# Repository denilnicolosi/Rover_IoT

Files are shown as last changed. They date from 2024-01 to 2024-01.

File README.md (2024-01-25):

# Rover_IoT
Progetto per il corso di Sistemi Operativi, implementazione di un rover con ESP32 e FreeRTOS che comunica mediante protocollo MQTT con una interfaccia web.

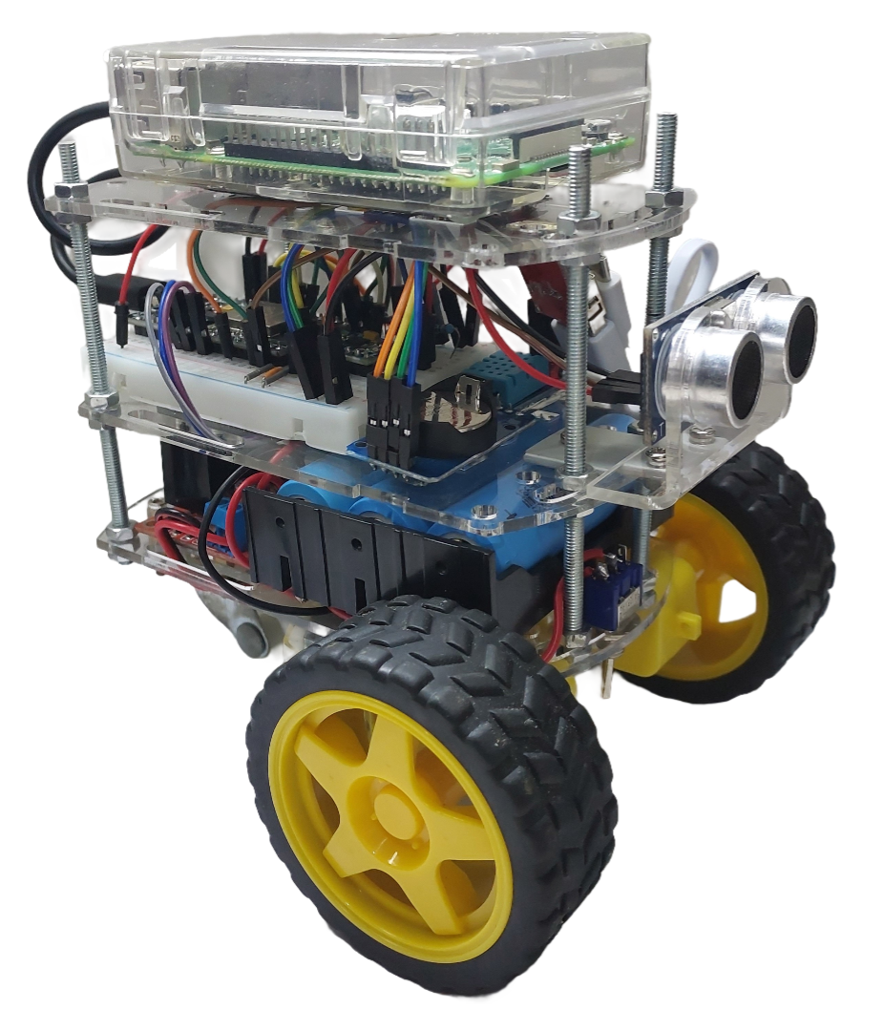
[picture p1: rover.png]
Rover


## Avvio Rapido
Per riprodurre il progetto in tutte le sue parti, realizzare il seguente schema elettrico:
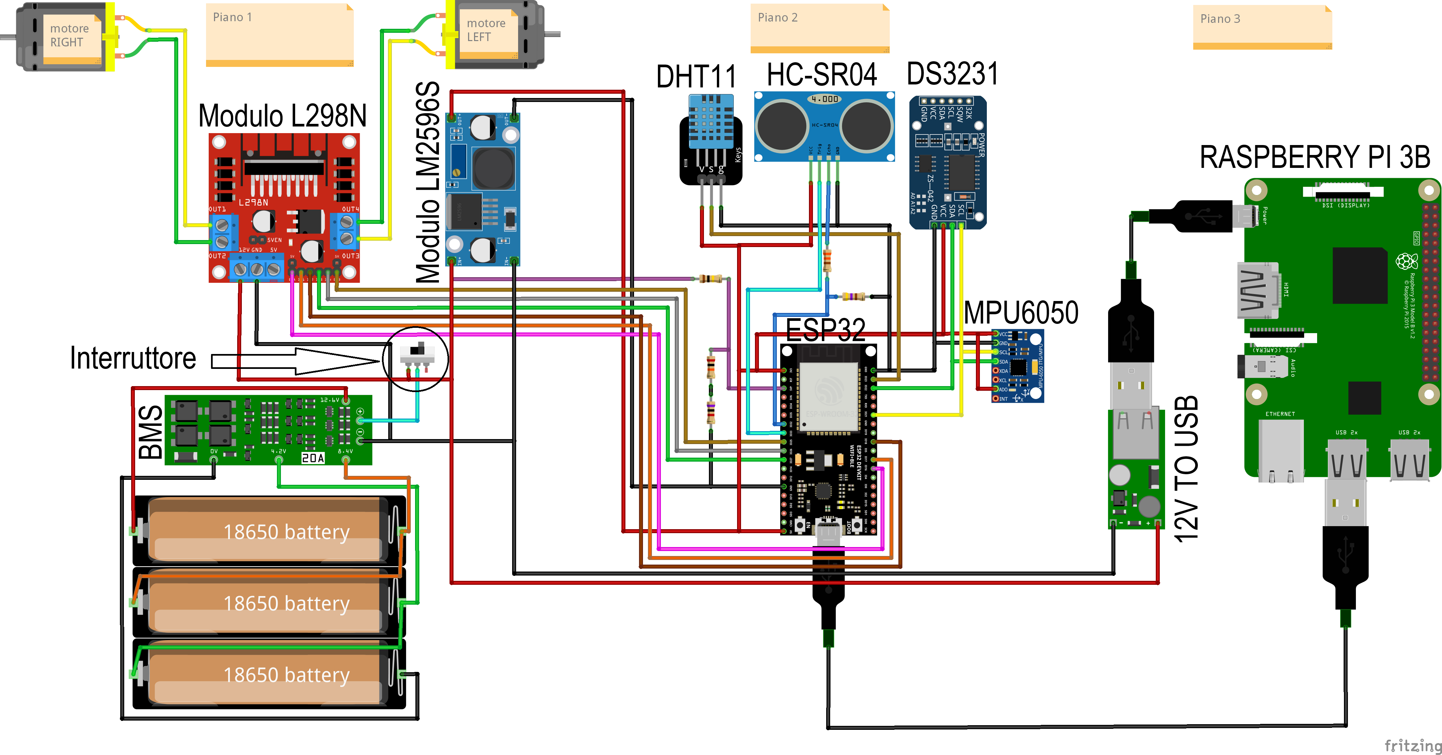
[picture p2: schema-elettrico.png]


Per avviare il progetto seguire i seguenti passaggi:
1. Clona il repository: `git clone https://github.com/denilnicolosi/Rover_IoT`
2. Naviga nella directory del progetto: `cd Rover_IoT`
3. Scaricare e avviare l'[IDE di Arduino](https://www.arduino.cc/en/software).
4. Aprire il [codice sorgente](ESP32/progetto_so.ino) dell'ESP32
5. Installare, tramite il gestore delle librerie, le seguenti dipendenze:
    - Adafruit_MPU6050: https://github.com/adafruit/Adafruit_MPU6050
    - Adafruit_Sensor: https://github.com/adafruit/Adafruit_Sensor
    - DS3231: https://github.com/NorthernWidget/DS3231
    - HCSR04: https://github.com/Martinsos/arduino-lib-hc-sr04
    - L298N: https://github.com/AndreaLombardo/L298N
    - DHT: https://github.com/adafruit/DHT-sensor-library
    - ArduinoJson: https://arduinojson.org/?utm_source=meta&utm_medium=library.properties
6. Eseguire l'upload del codice nell'ESP32.
7. Installare il sistema operativo Raspberry Pi OS nella memoria SD dedicata, utilizzando il [seguente tool](https://www.raspberrypi.com/software/) e inserire eventuali configurazioni (come nome utente, password e rete wifi)
8. Inserire la memoria SD nella Raspberry e dopo il primo avvio, creare un file python con il [seguente codice](Raspberry/mqtt_client.py) .
NB: nella funzione `client.connect()` va inserito l'hostname (o indirizzo IP) del broker MQTT configurato in seguito.
9. Per individuare la porta USB da inserire nella funzione `serial.Serial()`, è possibile utilizzare il [seguente codice](Raspberry/print_serial_port.py).
10. Creare il servizio per l'avvio automatico dello script, inserendo il file di configurazione [mqtt_client.service](mqtt_client.service) nel percorso predefinito `/lib/systemd/system/`.
11. Abilitare il servizio eseguendo in ordine i seguenti comandi:
    ```
    > sudo systemctl daemon-reload
    > sudo systemctl enable mqtt client.service
    > sudo systemctl start mqtt client.service
    > sudo systemctl status mqtt client.service
    ```
12. Creare una macchina virtuale Ubuntu, ad esempio utilizzando [VMware Workstation Player](https://www.vmware.com/it/products/workstation-player.html).
13. Installare il broker MQTT mosquitto con il comando `sudo apt install mosquitto mosquitto-clients`.
14. Da Ubuntu Software Center installare il pacchetto `node-red` e `mysql-workbench-community`.
15. Installare e configurare mysql con i seguenti comandi:
```
> sudo apt install mysql-server
> sudo systemctl start mysql.service
> sudo mysql
```
16. Impostare la password di root con il seguente comando:
```
mysql> ALTER USER 'root'@'localhost' IDENTIFIED WITH mysql_native_password BY 'pass';
mysql> exit;
```
17. Eseguire lo script per la configurazione in sicurezza:
```
sudo my_sql_secure_installation
```
18. Quindi creare un nuovo utente mysql per l'utilizzo dell'applicazione
```
> mysql -u root -p
mysql> CREATE USER 'nodered'@'localhost' IDENTIFIED BY 'n0dep4assw0rd';
mysql> GRANT PRIVILEGE ON *.* TO 'nodered'@'localhost';
mysql> FLUSH PRIVILEGES;
```
19. Creare il database con il comando:
```
mysql> CREATE DATABASE nodered;
```
20. Quindi creare la tabella con la query DDL:
```
mysql> CREATE TABLE 'nodered'.'sensors_history' (
        'id' INT NOT NULL AUTO_INCREMENT,
        'distance' DOUBLE NULL,
        'acceleration_x' DOUBLE NULL,
        'acceleration_y' DOUBLE NULL,
        'acceleration_z' DOUBLE NULL,
        'rotation_x' DOUBLE NULL,
        'rotation_y' DOUBLE NULL,
        'rotation_z' DOUBLE NULL,
        'timestamp' DATETIME NULL,
        'temperature' DOUBLE NULL,
        'humidity' DOUBLE NULL,
        'battery_voltage' DOUBLE NULL,
        PRIMARY KEY ('id'),
        UNIQUE INDEX 'id_UNIQUE' ('id' ASC) VISIBLE);
```
21. Accedere poi a Node-RED digitando nel browser il seguente indirizzo: `http://localhost:1880`

22. Installare, tramite 'Manage palette' le librerie:
    - node-red-dashboard
    - node-red-node-mysql

23. Importare la configurazione [dashboard.json](Node-RED/dashboard.json) cliccando sul menù la voce 'import'.
24. La dashboard sarà accessibile all'indirizzo `http://localhost:1800/ui`

Tutti gli approfondimenti per l'installazione si trovano nella [relazione del progetto](Relazione.pdf).

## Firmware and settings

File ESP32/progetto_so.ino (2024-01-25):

#include <Adafruit_MPU6050.h>
#include <Adafruit_Sensor.h>
#include <Wire.h>
#include <DS3231.h>
#include <HCSR04.h>
#include <L298N.h>
#include <DHT.h>
#include <ArduinoJson.h>

// Definizione dei pin GPIO ESP32
#define HCSR04_TRIGGER_PIN 32
#define HCSR04_ECHO_PIN 33
#define DHT11_PIN 23
#define BATTERY_PIN 36
#define L_MOTOR_EN_PIN 25
#define L_MOTOR_IN1_PIN 26
#define L_MOTOR_IN2_PIN 27
#define R_MOTOR_EN_PIN 16
#define R_MOTOR_IN1_PIN 17
#define R_MOTOR_IN2_PIN 18

// Defininizione delle costanti utilizzate
#define DELAY_SEND_SENSOR_DATA_MS 2000
#define DELAY_FUNCTION_MODE_MS 50
#define DELAY_RECEIVE_DATA_MS 100
#define SAFETY_DISTANCE_CM 20

// Dichiarazione degli oggetti utilzzati
Adafruit_MPU6050 mpu;
RTClib myRTC;
DS3231 myClock;
DHT dht11(DHT11_PIN, DHT11);
L298N l_motor(L_MOTOR_EN_PIN, L_MOTOR_IN1_PIN, L_MOTOR_IN2_PIN);
L298N r_motor(R_MOTOR_EN_PIN, R_MOTOR_IN1_PIN, R_MOTOR_IN2_PIN );
UltraSonicDistanceSensor distanceSensor(HCSR04_TRIGGER_PIN, HCSR04_ECHO_PIN); 
StaticJsonDocument<250> docOutput; // Utilizzato il tool https://arduinojson.org/v6/assistant per calcolare la capacità del documento json.
StaticJsonDocument<250> docInput;

//definizione del semaforo
SemaphoreHandle_t xMutex;

// Variabili ed enum utilizzati
sensors_event_t a, g, temp;

enum function_mode{
  AUTO = 0 ,
  MAN = 1
} function_mode_selected;

enum command{
  FORWARD = 0,
  BACKWARD = 1,
  RIGHT = 2,
  LEFT = 3,
  STOP = 4
} command_received;


void taskFunctionMode(void *pvParameters){
  TickType_t xLastWakeTime = xTaskGetTickCount();
  while (1){    
    if(function_mode_selected == AUTO){
      xSemaphoreTake(xMutex, portMAX_DELAY);      
      if(distanceSensor.measureDistanceCm()<=SAFETY_DISTANCE_CM){
        r_motor.stop();
        l_motor.stop();
        vTaskDelay(500 / portTICK_PERIOD_MS);      
        //random rotate
        r_motor.forward();
        l_motor.backward();
        vTaskDelay(random(300,800) / portTICK_PERIOD_MS);
        r_motor.stop();
        l_motor.stop();
        vTaskDelay(500 / portTICK_PERIOD_MS);  
      }else{
        r_motor.forward();
        l_motor.forward();    
      } 
      xSemaphoreGive(xMutex);     
    }
    else
    {  
      switch(command_received){
        case FORWARD:
            xSemaphoreTake(xMutex, portMAX_DELAY);
            if(distanceSensor.measureDistanceCm()<=SAFETY_DISTANCE_CM){            
              r_motor.stop();
              l_motor.stop(); 
            }else{              
              r_motor.forward();
              l_motor.forward();
            } 
            xSemaphoreGive(xMutex);         
          break;
        case BACKWARD:
          r_motor.backward();
          l_motor.backward(); 
          break;
        case RIGHT:
          r_motor.backward();
          l_motor.forward(); 
          break;
        case LEFT:
          r_motor.forward();
          l_motor.backward(); 
          break;
        case STOP:
          r_motor.stop();
          l_motor.stop(); 
          break;  

        default:
          r_motor.stop();
          l_motor.stop(); 
          
      }      
    }
    vTaskDelayUntil( &xLastWakeTime, pdMS_TO_TICKS(DELAY_FUNCTION_MODE_MS));    
  }
}


void taskRiceviDati(void *pvParameters){
  TickType_t xLastWakeTime = xTaskGetTickCount();
  while (1){    
    if(Serial.available()){
      DeserializationError err = deserializeJson(docInput, Serial);
      if (err == DeserializationError::Ok) 
      {      
        if(!docInput["rtc_sync_unixtime"].isNull()){                   
          time_t epoch = (time_t)docInput["rtc_sync_unixtime"].as<long>();
          myClock.setEpoch(epoch);
        }
        if(!docInput["function_mode_auto"].isNull()){
          if(docInput["function_mode_auto"].as<String>()=="true"){
            function_mode_selected=AUTO;          
          }else{
            function_mode_selected=MAN;            
          }
        }
        if(!docInput["movement_command"].isNull()){
          command_received = (command) docInput["movement_command"].as<int>();         
        }
        if(!docInput["speed"].isNull()){
          int speed=docInput["speed"].as<int>();
          if(speed>0 && speed<=100){
            //mapping della velocità che viene ricevuta in 0-100% al range pwm in 0-255
            speed = map(speed, 0, 100, 0, 255);
            l_motor.setSpeed(speed);
            r_motor.setSpeed(speed);           
          }
        }
      } 
      else 
      {        
        // Flush all bytes in the "link" serial port buffer
        while (Serial.available() > 0)
          Serial.read();
      }
    }
    vTaskDelayUntil( &xLastWakeTime, pdMS_TO_TICKS(DELAY_RECEIVE_DATA_MS));       
  }
}

void taskInvioDati(void *pvParameters){
  TickType_t xLastWakeTime = xTaskGetTickCount();
  while (1){    
    mpu.getEvent(&a, &g, &temp);   
    xSemaphoreTake(xMutex, portMAX_DELAY);
    docOutput["distance"]=distanceSensor.measureDistanceCm();
    xSemaphoreGive(xMutex);
    docOutput["acceleration"]["x"]=a.acceleration.x;
    docOutput["acceleration"]["y"]=a.acceleration.y;
    docOutput["acceleration"]["z"]=a.acceleration.z;
    docOutput["rotation"]["x"]=g.gyro.x;
    docOutput["rotation"]["y"]=g.gyro.y;
    docOutput["rotation"]["z"]=g.gyro.z;
    docOutput["unixtime"]=myRTC.now().unixtime();
    docOutput["temperature"]=dht11.readTemperature(); 
    docOutput["humidity"]=dht11.readHumidity();
    docOutput["battery"]["voltage"]=readVoltage();
    serializeJson(docOutput, Serial);
    Serial.println();

    vTaskDelayUntil( &xLastWakeTime, pdMS_TO_TICKS(DELAY_SEND_SENSOR_DATA_MS)); 
  }
}

float readVoltage(){
  return (float)analogRead(BATTERY_PIN) / 4096 * 17 ;
}

void setup(void) {
  Serial.begin(115200); 
  Wire.begin();  
  if (!mpu.begin(0x69)) {
    Serial.println("Failed to find MPU6050 chip");  
  }else{
    Serial.println("MPU6050 Found!"); 
  }
  dht11.begin();  

  function_mode_selected=MAN;
  command_received=STOP;
  l_motor.setSpeed(70);
  r_motor.setSpeed(70);

  xMutex = xSemaphoreCreateMutex();
  
  xTaskCreate(taskRiceviDati, "Task ricezione dati", 5000, NULL, 2, NULL);  
  xTaskCreate(taskFunctionMode, "Task modalità di funzionamento", 5000, NULL, 3, NULL);
  xTaskCreate(taskInvioDati, "Task invio dati", 5000, NULL, 1, NULL);
}

void loop () {}

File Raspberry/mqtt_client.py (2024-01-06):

import serial
import simplejson as json
import paho.mqtt.client as mqtt

def on_connect(client, userdata, flags, rc):
    print("Connected to host '", client._host, "'") 
    client.subscribe("movement_command")
    client.subscribe("speed")
    client.subscribe("function_mode_auto")
    client.subscribe("rtc_sync_unixtime")

def on_message(client, userdata, msg):
    #write to serial port json with key msg.topic and value msg.payload
    ser.write(json.dumps({msg.topic:msg.payload}).encode('utf-8'))
    print("Serial out: ",json.dumps({msg.topic:msg.payload}))

client = mqtt.Client()
client.on_connect = on_connect
client.on_message = on_message

client.connect("ubuntu", 1883, 60)
client.loop_start()
buffer=""

try:        

    ser = serial.Serial('/dev/ttyUSB0',baudrate=115200)
    if ser.isOpen():
        print("Serial port opened: " + ser.portstr)
   
        ser.reset_input_buffer()

        while True:
            try:
                if ser.inWaiting()>0:
                    buffer = ser.readline().decode('utf-8').rstrip()
                    print ("Serial in: ",buffer)
                    data=json.loads(buffer)                
                    client.publish(topic = "rover_output", payload = buffer, qos=1) 
            except Exception as e:
                print(e)

except KeyboardInterrupt:
    print(" Stop program ...")
    ser.close()
except serial.SerialException:
    print(" Serial error")

client.loop_stop()
client.disconnect()

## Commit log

2024-01-06 Materiale progetto
    [schema elettrico.fzz]
2024-01-08 Fixed the color bands of the battery voltage divider resistor R1
